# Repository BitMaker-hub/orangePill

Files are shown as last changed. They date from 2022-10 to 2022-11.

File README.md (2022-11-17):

# The Orange Pill
## Description
The OrangePill is a new social mechanism to onboard, gift, transfer or sell bitcoin in a physical, safe and reusable way.

It is a real HW Orange Pill that can be used in a community as cash. It also can be the entry point for those who doesn't know anything about Bitcoin and the best, it can be used as many times you want. 

## ATTENTION! This project is still in developement and must be tested on tesnet

## How can I use it?
Receive 💊 ➡️ Create 🌱💦 ➡️ Save ₿ 🔐➡️ Give it away

Receive 🔐 💊 ➡️ Unlock 🌱 ₿ ➡️ Reboot 💊 ➡️ Repeat with others 🔄

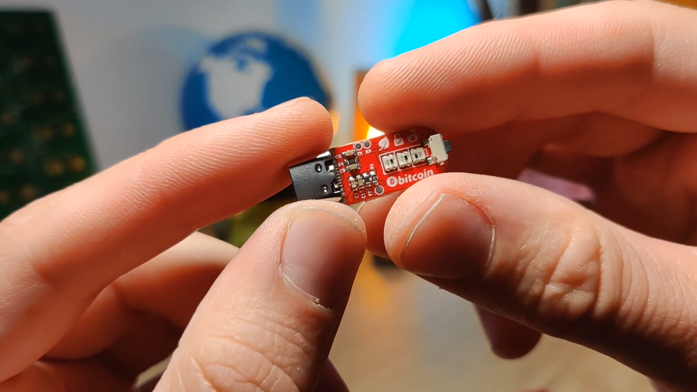
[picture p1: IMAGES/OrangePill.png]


## How it works?
### PILL AS A KEYBOARD
The OrangePill works as a input HID device, it emulates keyboard strokes. Every time you push it's button sends keystrokes.
It don't need any specific app to work. Works on any device or pc, you just need to open a notepad or any text editor and press the pill button.

Posible inputs:

- One push:   Shows current status, display options and show xpub or mnemonic depending of it's state.
- Two pushes: Shows # times pill was used, public gpg of interal hw + signed message.
- Hold 5 sec: Depending of it's state > Start seed generation / Unlock seed / Reset pill
- SHAKE: During seed generation or seed unlock.

##PILL STATES

The orangePill has currently three sates.

VIRGIN: No seed present. Needs to generate entropy. 
LOCKED: Seed present. When you make one push you can only see xpub.
UNLOCKED: Seed revealed. When you make one push you can see mnemonic.

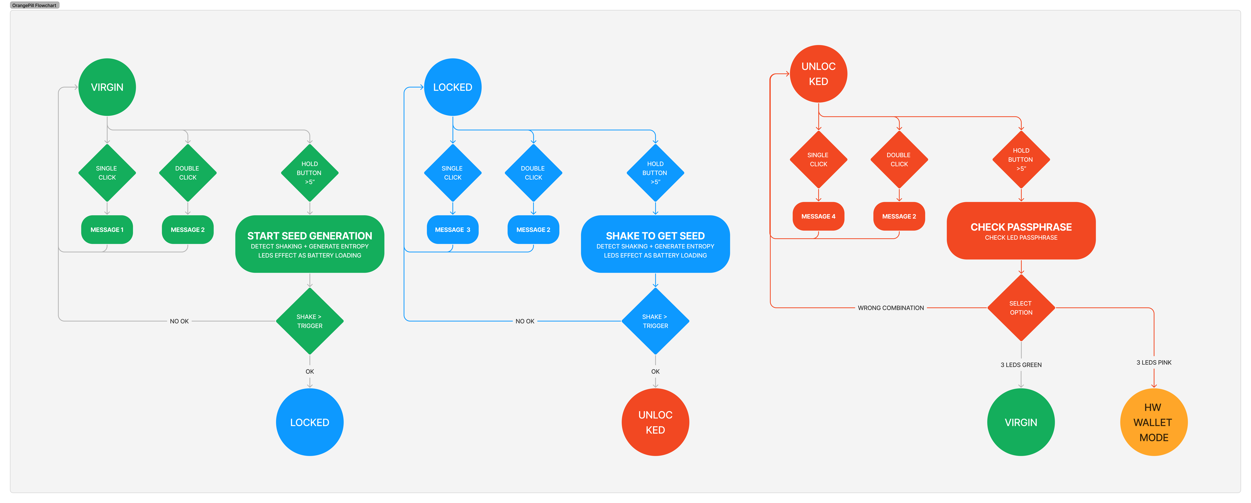
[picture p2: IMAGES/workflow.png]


## HW Specifictions
- ESP32S2
- LEDs WS2812B
- Button
- Accelerometer KXTJ3-1057
- ATTEC608A



## Libraires
- Main library -> <a href="https://www.arduino.cc/reference/en/libraries/ubitcoin/">uBitcoin</a>
- Adafruit_NeoPixel
- kxtj3-1057
- hidkeyboard

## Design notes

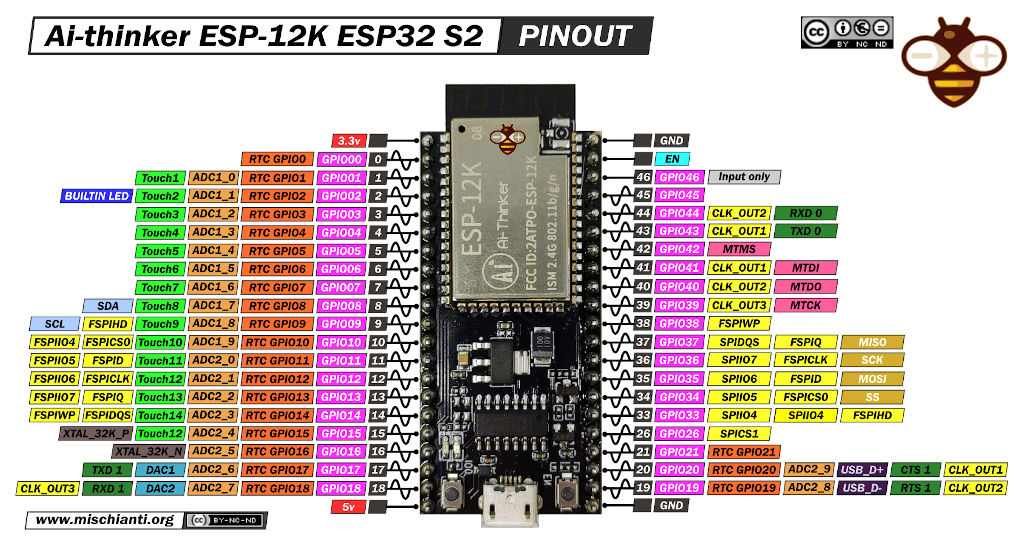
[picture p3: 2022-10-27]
SOFTWARE/Ai-thinker-ESP-12K-ESP32-S2-pinout-mischianti-low.jpg

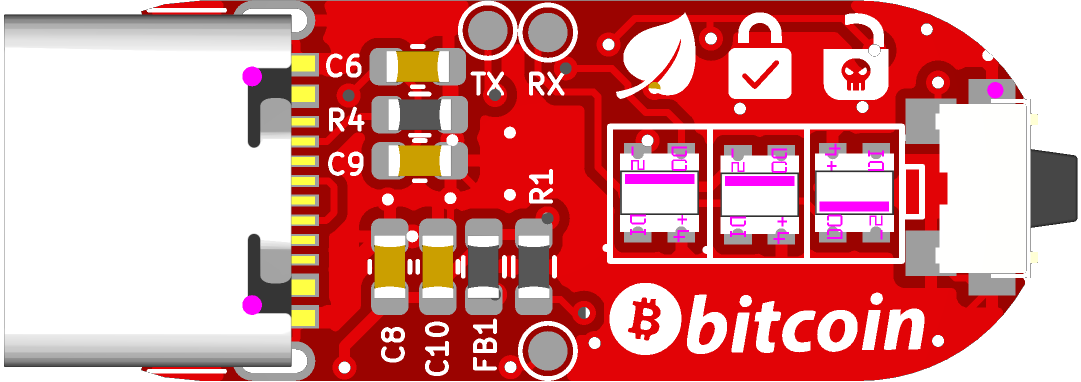
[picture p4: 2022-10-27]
PCB/Images/8e9199de238b4486b2469e8c72638f28.png

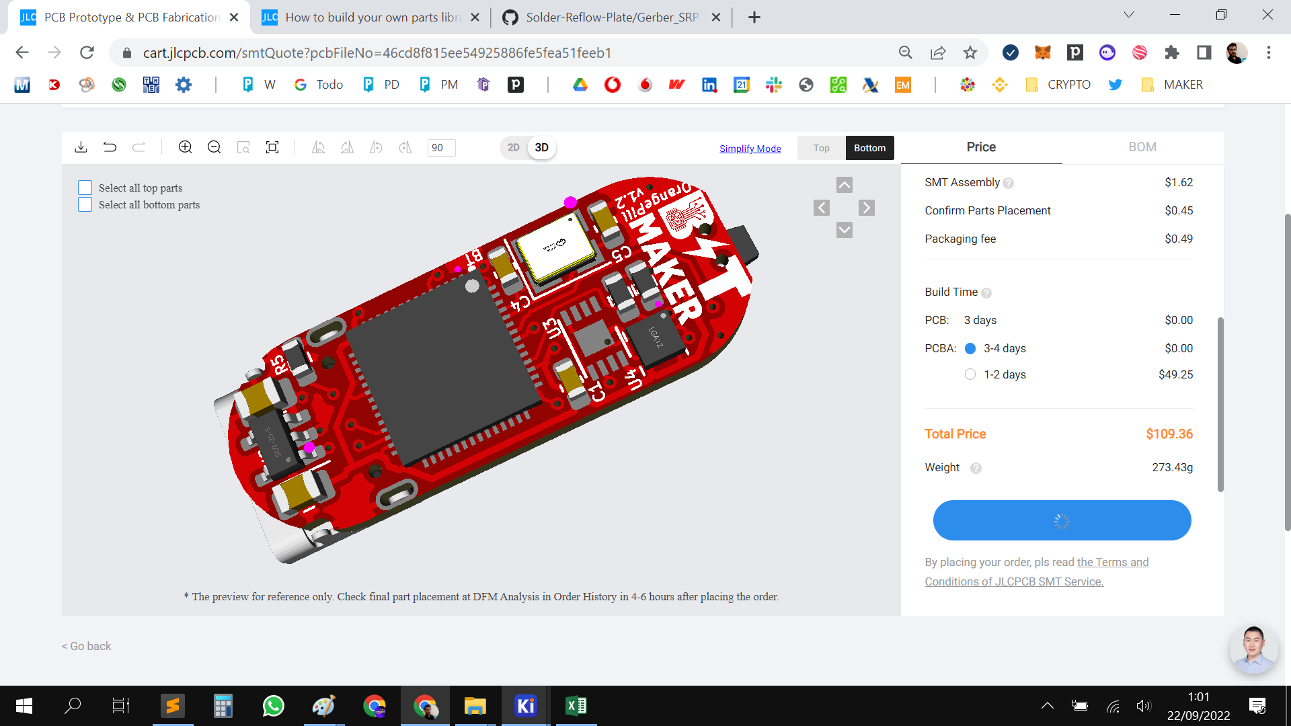
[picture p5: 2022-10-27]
PCB/Images/orangepill.png

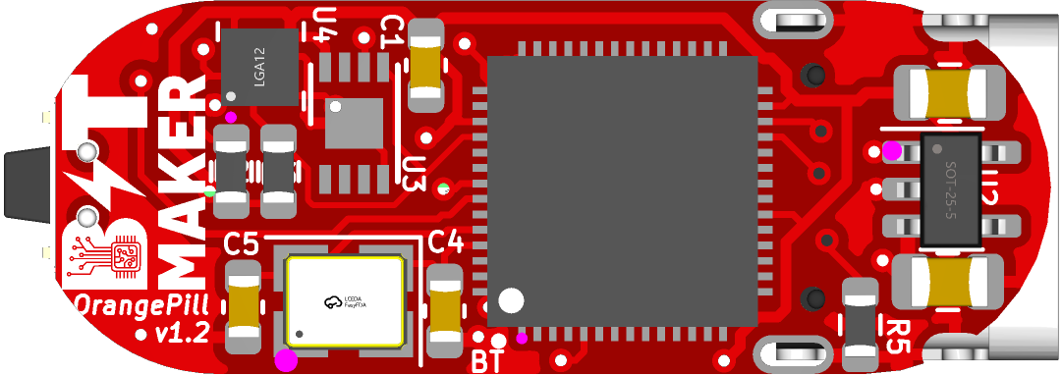
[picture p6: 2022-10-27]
PCB/Images/d6f5790a019c45c9bf4b03b32c207812.png

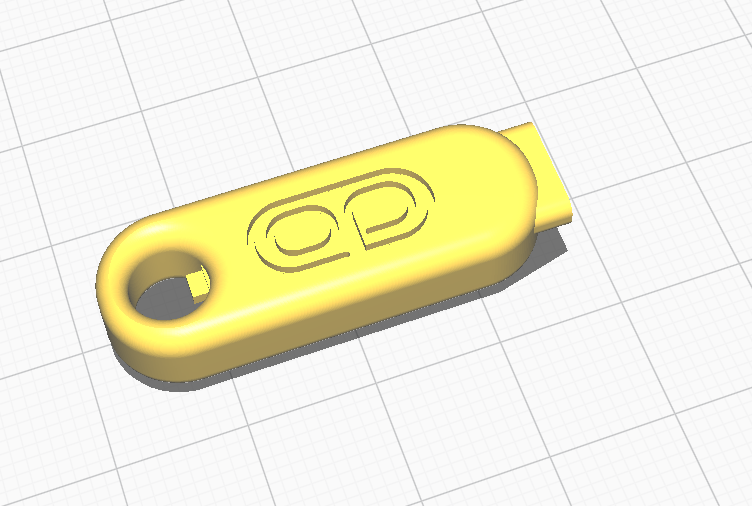
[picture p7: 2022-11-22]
IMAGES/pillEpoxi.png

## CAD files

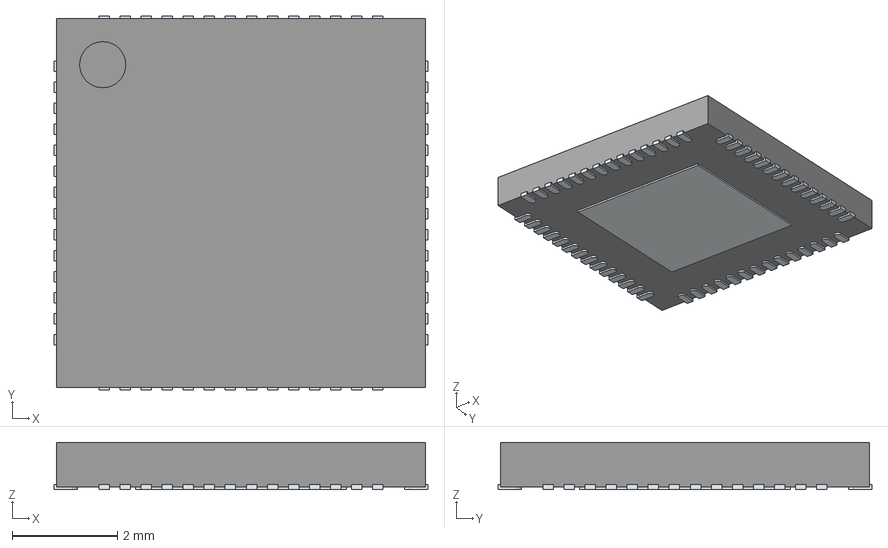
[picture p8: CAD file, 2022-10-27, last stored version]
PCB/Llibreries/ESP32-S2FN4R2.stp
7.10 x 7.10 x 0.9 mm
ThermalPin
PinsArrayLR
PinsArrayTB

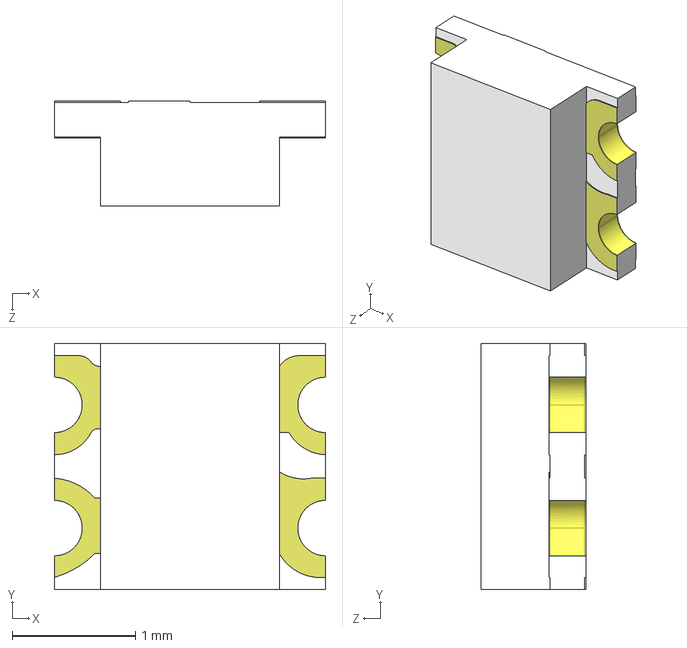
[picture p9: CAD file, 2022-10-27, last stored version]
PCB/Llibreries/WS2812B-2020.stp
2.20 x 2.00 x 0.85 mm

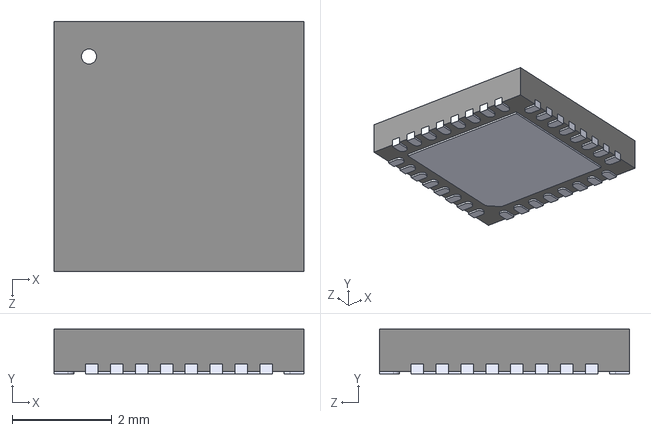
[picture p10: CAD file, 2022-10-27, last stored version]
PCB/Llibreries/ESP32-C3FH4.step
5.00 x 0.9 x 5.00 mm

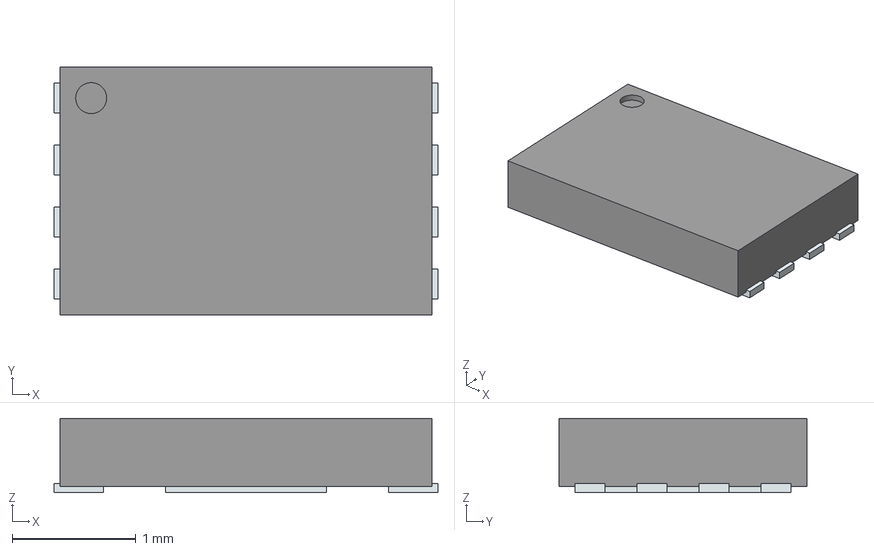
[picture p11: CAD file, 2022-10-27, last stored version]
PCB/Llibreries/ATECC508A-MAHCZ-S.stp
3.10 x 2.00 x 0.6 mm
ThermalPin
PinsArrayLR

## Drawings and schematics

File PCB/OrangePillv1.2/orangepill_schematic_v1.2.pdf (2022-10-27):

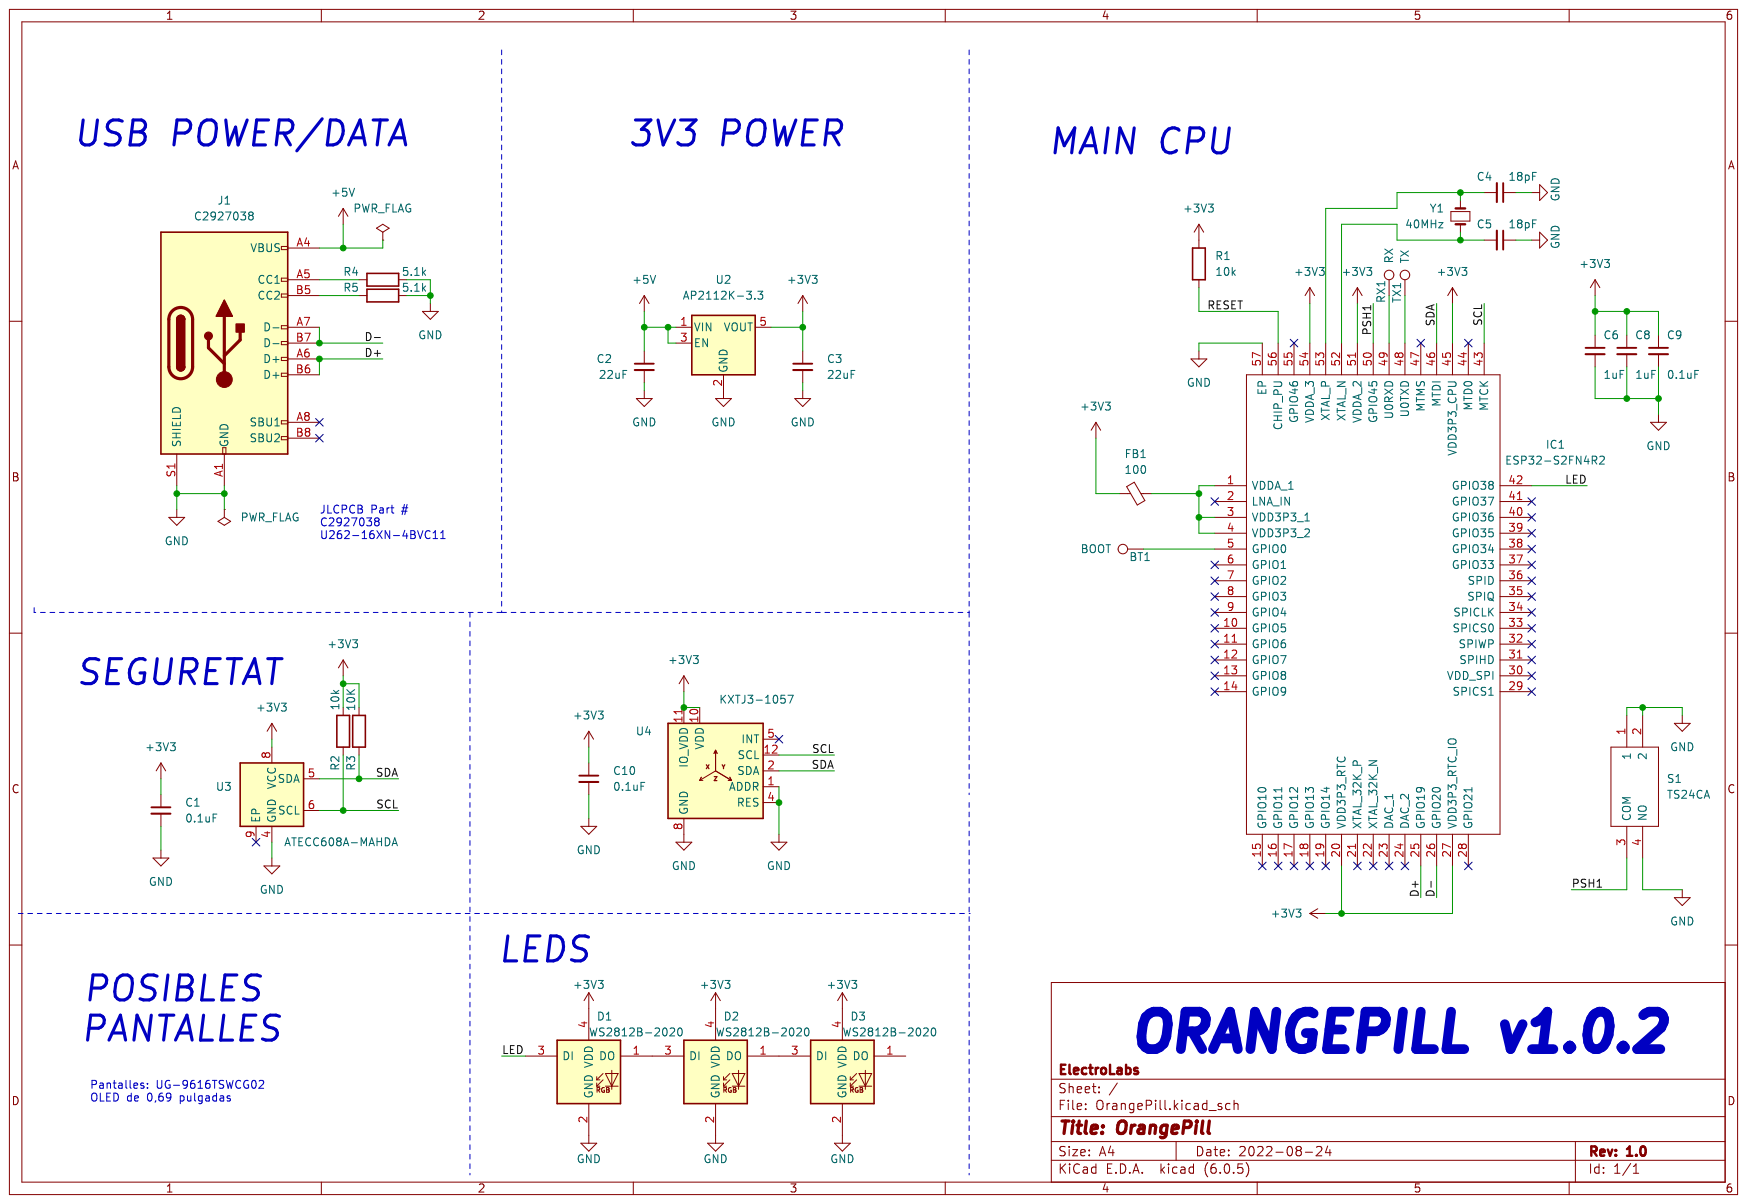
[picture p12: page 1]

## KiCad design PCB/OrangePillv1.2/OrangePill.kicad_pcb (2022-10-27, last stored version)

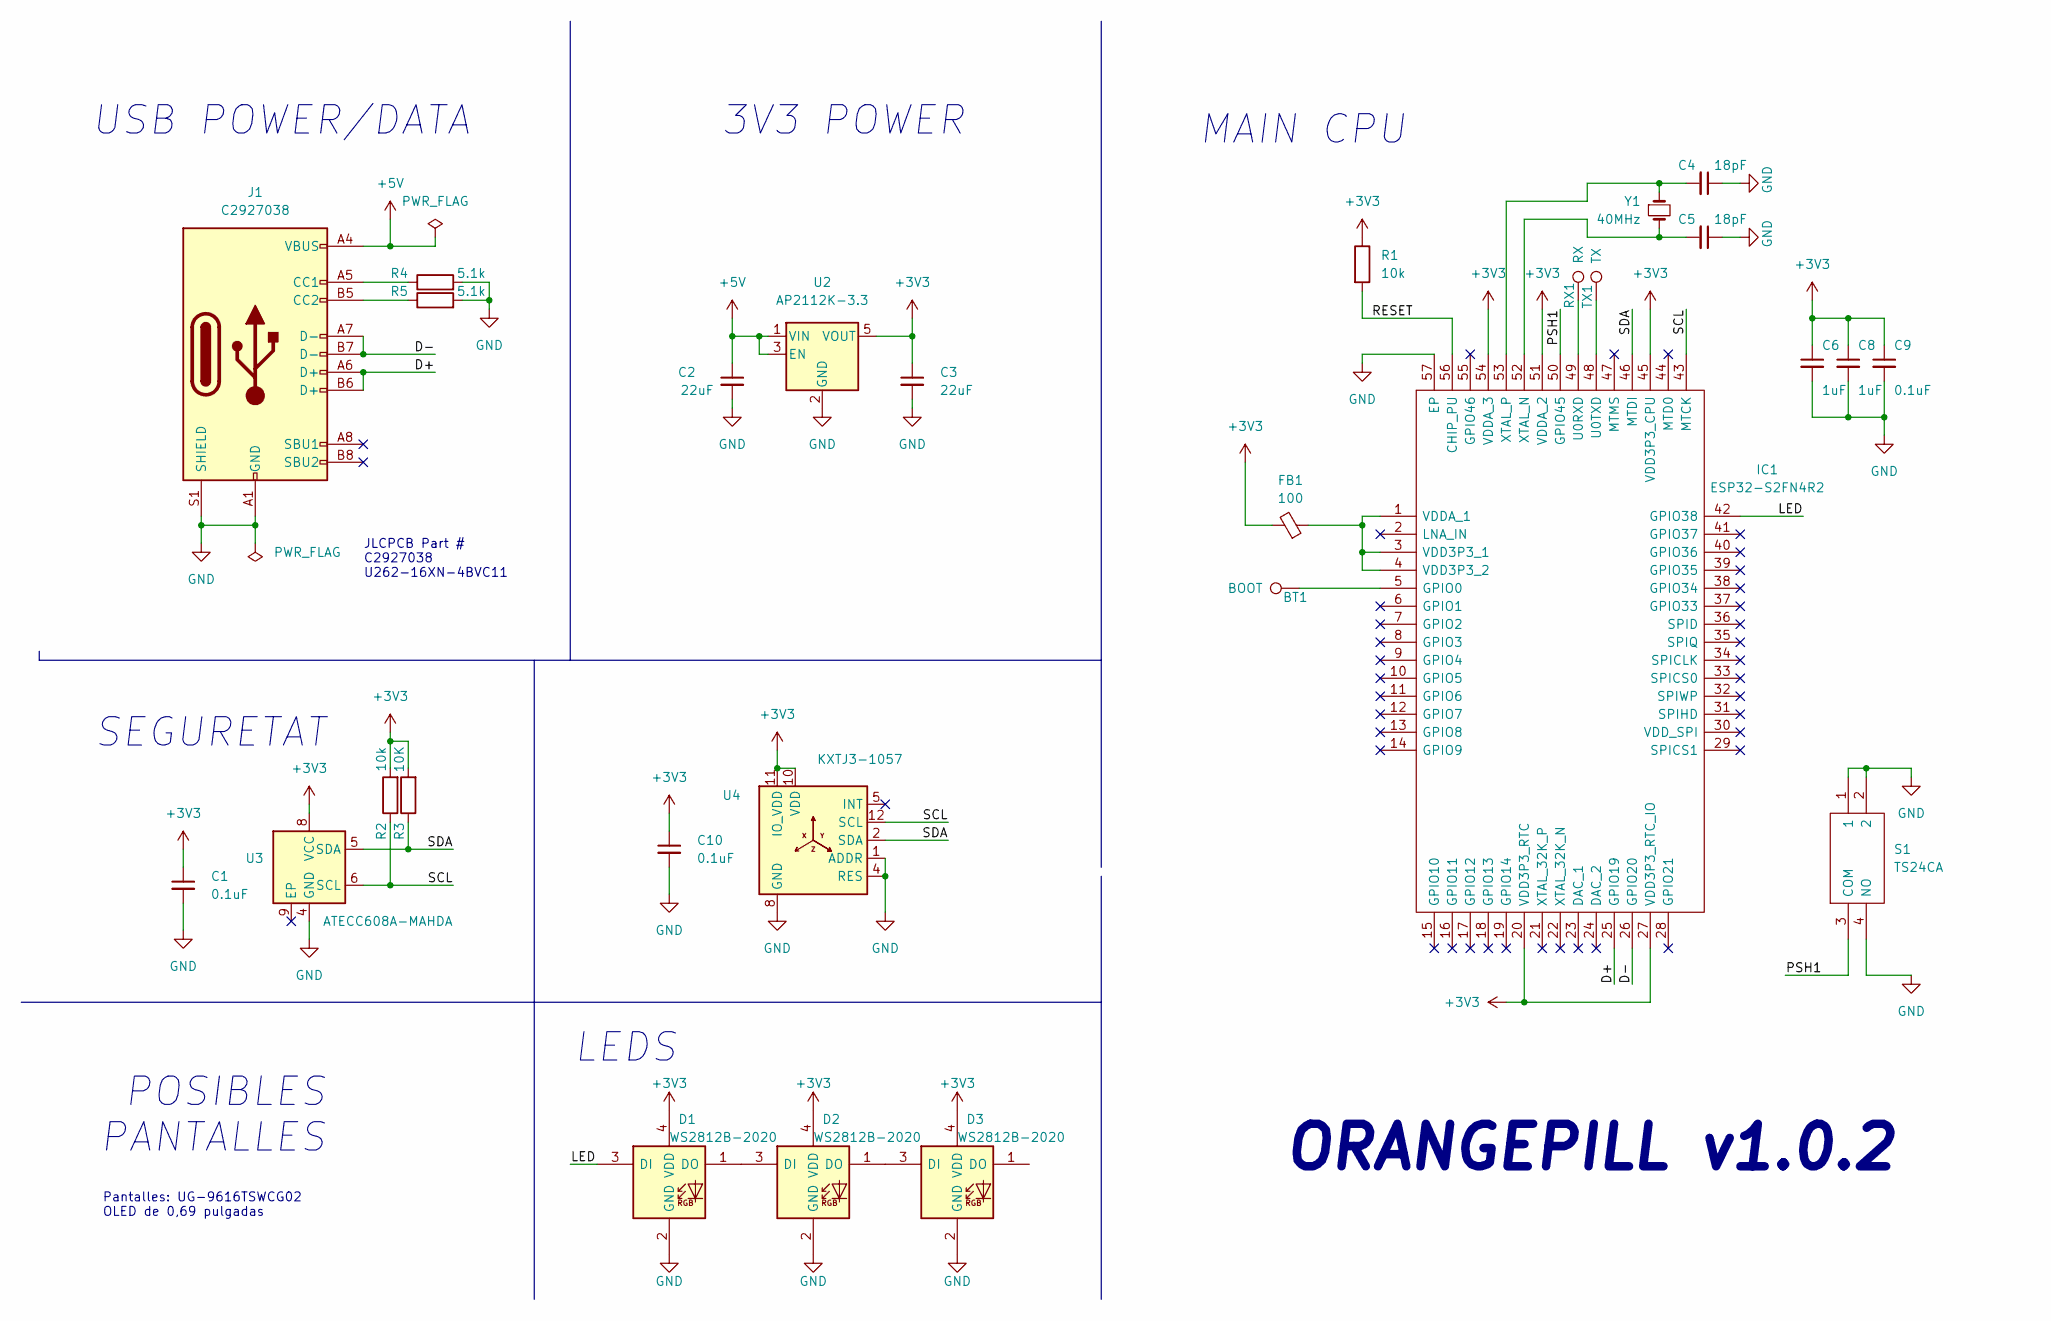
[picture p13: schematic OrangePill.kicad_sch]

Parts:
BT1: BOOT; TestPoint_Pad_D1.5mm
C1, C9, C10: 0.1uF; C_0603_1608Metric
C2, C3: 22uF; C_0805_2012Metric
C4, C5: 18pF; C_0603_1608Metric
C6, C8: 1uF; C_0603_1608Metric
D1, D2, D3: WS2812B-2020; WS2812B2020; Manufacturer_Part_Number WS2812B-2020
FB1: 100; R_0603_1608Metric
IC1: ESP32-S2FN4R2; QFN40P700X700X90-57N-D; Manufacturer_Part_Number ESP32-S2FN4R2; Mouser Part Number 356-ESP32-S2FN4R2
J1: C2927038; USB_C_Receptacle_XKB_U262-16XN-4BVC11
R1, R2: 10k; R_0603_1608Metric
R3: 10K; R_0603_1608Metric
R4, R5: 5.1k; R_0603_1608Metric
RX1: RX; TestPoint_Pad_D1.0mm
S1: TS24CA; Manufacturer_Part_Number TS24CA
TX1: TX; TestPoint_Pad_D1.0mm
U2: AP2112K-3.3; SOT-23-5
U3: ATECC608A-MAHDA; DFN-8-1EP_3x2mm_P0.5mm_EP1.3x1.5mm
U4: KXTJ3-1057; Kionix_LGA-12_2x2mm_P0.5mm_LayoutBorder2x4y
Y1: 40MHz; Crystal_SMD_3225-4Pin_3.2x2.5mm

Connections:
+3V3: C1.1, C3.1, C6.1, C8.1, C9.1, C10.1, D1.4 (VDD), D2.4 (VDD), D3.4 (VDD), FB1.2, IC1.20 (VDD3P3_RTC), IC1.27 (VDD3P3_RTC_IO), IC1.45 (VDD3P3_CPU), IC1.51 (VDDA_2), IC1.54 (VDDA_3), R1.1, R2.2, R3.2, U2.5 (VOUT), U3.8 (VCC), U4.3 (IO_VDD), U4.7 (VDD), U4.10 (VDD), U4.11 (IO_VDD)
+5V: C2.1, J1.A4 (VBUS), J1.A9 (VBUS), J1.B4 (VBUS), J1.B9 (VBUS), U2.1 (VIN), U2.3 (EN)
/D+: IC1.25 (GPIO19), J1.A6 (D+), J1.B6 (D+)
/D-: IC1.26 (GPIO20), J1.A7 (D-), J1.B7 (D-)
/LED: D1.3 (DI), IC1.42 (GPIO38)
/PSH1: IC1.50 (GPIO45), S1.3 (COM)
/RESET: IC1.56 (CHIP_PU), R1.2
/SCL: IC1.43 (MTCK), R2.1, U3.6 (SCL), U4.12 (SCL)
/SDA: IC1.46 (MTDI), R3.1, U3.5 (SDA), U4.2 (SDA)
GND: C1.2, C2.2, C3.2, C4.1, C5.1, C6.2, C8.2, C9.2, C10.2, D1.2 (GND), D2.2 (GND), D3.2 (GND), IC1.57 (EP), J1.A1 (GND), J1.A12 (GND), J1.B1 (GND), J1.B12 (GND), J1.S1 (SHIELD), R4.2, R5.2, S1.1, S1.2, S1.4 (NO), U2.2 (GND), U3.4 (GND), U3.9 (EP), U4.1 (ADDR), U4.4 (RES), U4.6 (GND), U4.8 (GND), U4.9 (GND)
unnamed: BT1.1, IC1.5 (GPIO0)
unnamed: C4.2, IC1.53 (XTAL_P), Y1.1
unnamed: C5.2, IC1.52 (XTAL_N), Y1.2
unnamed: D1.1 (DO), D2.3 (DI)
unnamed: D2.1 (DO), D3.3 (DI)
unnamed: FB1.1, IC1.1 (VDDA_1), IC1.3 (VDD3P3_1), IC1.4 (VDD3P3_2)
unnamed: IC1.48 (U0TXD), TX1.1
unnamed: IC1.49 (U0RXD), RX1.1
unnamed: J1.A5 (CC1), R4.1
unnamed: J1.B5 (CC2), R5.1

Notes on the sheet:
ORANGEPILL v1.0.2
POSIBLES PANTALLES
JLCPCB Part # C2927038 U262-16XN-4BVC11
LEDS
Pantalles: UG-9616TSWCG02 OLED de 0,69 pulgadas
SEGURETAT
MAIN CPU
USB POWER/DATA
3V3 POWER

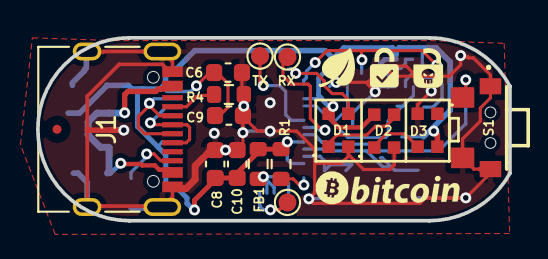
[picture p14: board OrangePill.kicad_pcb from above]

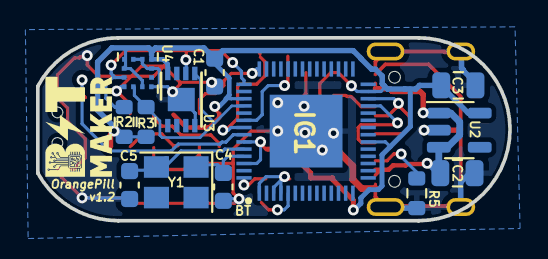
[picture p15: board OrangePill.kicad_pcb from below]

Board: 2 copper layers, 26.2 x 10.2 mm, 29 parts (13 on the bottom side), 20 nets.

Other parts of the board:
fiducial: Fiducial_0.5mm_Mask1.5mm

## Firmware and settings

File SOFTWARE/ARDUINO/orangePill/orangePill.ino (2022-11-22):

#include "gpio.h"
#include "btc.h"
#include "workflow.h"
#include "GlobalVARS.h"

sPILL myPill;

void setup() {

  pinMode(BUTTON_PIN, INPUT_PULLUP);            // Init pushbutton pin
  Serial.begin(SERIAL_BAUD);                    // Init Serial port
  EEPROMsetup();                                // Init EEPROMdata
  LedSetup();                                   // Init neopixels leds
  AccSetup();                                   // Init Accelerometer
  initUSBKeyboard();                            // Init USB Keyboard emulation
  initWallet();                                 // Init wallet data
}


void loop() {
  showInitEffect();

  while(true){
    int buttonState = checkButton();

    switch(myPill.State){
      case STATE_VIRGIN:   doVirginState(buttonState); break;
      case STATE_SEEDING:  doSeedingState(buttonState); break;
      case STATE_LOCKED:   doLockedState(buttonState); break;
      case STATE_OPENPILL: doOpenPill(buttonState); break;
      case STATE_UNLOCKED: doUnlockedState(buttonState); break;
    }
    delay(10);
  }
}

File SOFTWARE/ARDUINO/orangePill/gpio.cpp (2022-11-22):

#include <Adafruit_NeoPixel.h>
#include <EEPROM.h>
#include "GlobalVARS.h"
#include "gpio.h"
#include "kxtj3-1057.h"
#include "Wire.h"

// Enable Serial debbug on Serial UART to see registers wrote
#define KXTJ3_DEBUG Serial

float   sampleRate = 6.25;  // HZ - Samples per second - 0.781, 1.563, 3.125, 6.25, 12.5, 25, 50, 100, 200, 400, 800, 1600Hz
uint8_t accelRange = 2;     // Accelerometer range = 2, 4, 8, 16g

// Declare our NeoPixel strip object:
Adafruit_NeoPixel strip(LED_COUNT, LED_PIN, NEO_GRB + NEO_KHZ800);

KXTJ3 myACC(0x0E); // Address can be 0x0E or 0x0F

extern sPILL myPill;

/***********************💊 EEPROM DATA ******************************/

void EEPROMsetup(){
  
  EEPROM.begin(EEPROM_SIZE);
  
  /********💊 READ PILL STATE ************/
  myPill.State = EEPROM.read(0);
  if(myPill.State>STATE_UNLOCKED) myPill.State = STATE_VIRGIN;
  
  /********💊 READ MNMONIC ************/
  String mnemonic="";
  if(EEPROM.read(1) == STX){
    for(uint16_t i=2; i<400; i++){
      uint8_t nm = EEPROM.read(i);
      if(nm == ETX) break;
      mnemonic = mnemonic + char(nm);
    }
  }
  myPill.mnemonic = mnemonic;
  Serial.print("Current mnemonic: "); Serial.println(mnemonic);
  
}

void saveMnemonic(String mnemonic){

  uint16_t i;
  for(i=2; i<(mnemonic.length()+2); i++){
    EEPROM.write(i, mnemonic[i-2]);
  }
  EEPROM.write(i,3);
  EEPROM.write(1,STX);
  delay(10);
  EEPROM.commit();
}

/***********************💊 LED EFFECTS ******************************/
void LedSetup() {
  strip.begin();           // INITIALIZE NeoPixel strip object (REQUIRED)
  strip.show();            // Turn OFF all pixels ASAP
  strip.setBrightness(40); // Set BRIGHTNESS to about 1/5 (max = 255)
}

void colorWipe(uint32_t color, int wait) {
  for(int i=0; i<strip.numPixels(); i++) { // For each pixel in strip...
    strip.setPixelColor(i, color);         //  Set pixel's color (in RAM)
    strip.show();                          //  Update strip to match
    delay(wait);                           //  Pause for a moment
  }
}
void colorWipeBack(uint32_t color, int wait) {
  for(int i=strip.numPixels(); i>0; i--) { // For each pixel in strip...
    strip.setPixelColor(i-1, color);         //  Set pixel's color (in RAM)
    strip.show();                          //  Update strip to match
    delay(wait);                           //  Pause for a moment
  }
}

// Rainbow cycle along whole strip. Pass delay time (in ms) between frames.
void rainbow(int wait) {
  for(long firstPixelHue = 0; firstPixelHue < 1*65536; firstPixelHue += 256) {
    strip.rainbow(firstPixelHue);
    strip.show(); // Update strip with new contents
    delay(wait);  // Pause for a moment
  }
}

//Init efect on leds
void showInitEffect(){
                            //RED-GREEN-BLUE
  //uint32_t color = strip.Color(0,   255,   0); //Green
  //rainbow(6); 
  setLedsColor(COLOR_NONE, COLOR_NONE, COLOR_NONE);
  delay(100);

  uint32_t color = COLOR_GREEN;
  switch(myPill.State){
     case STATE_VIRGIN:  color = COLOR_GREEN; break;
     case STATE_LOCKED: color = COLOR_BLUE; break;
     case STATE_UNLOCKED: color = COLOR_RED; break;
  }
  
  colorWipe(color, 100);
  delay(100);
  colorWipe(COLOR_NONE, 100);
  colorWipeBack(color, 100);
  delay(100);
  colorWipeBack(COLOR_NONE, 100);
}

void setLedsColor(int Led1, int Led2, int Led3) {
    strip.setPixelColor(0, Led1);
    strip.setPixelColor(1, Led2);
    strip.setPixelColor(2, Led3);
    strip.show();
}

//Blink all 3 leds 
void blinkAllLeds(uint32_t color){
  for(int i=0; i<4; i++){
    strip.setPixelColor(0, color);
    strip.setPixelColor(1, color);
    strip.setPixelColor(2, color);
    strip.show();
    delay(150);
    strip.setPixelColor(0, COLOR_NONE);
    strip.setPixelColor(1, COLOR_NONE);
    strip.setPixelColor(2, COLOR_NONE);
    strip.show();
    delay(150);
  }
  delay(500);
}


/*********************💊 ACCELEROMETER *****************/
void AccSetup(){
  Wire.begin(I2C_SDA, I2C_SCL); 
  
  if( myACC.begin(sampleRate, accelRange) != 0 )
  {
    Serial.print("Failed to initialize IMU.\n");
  }
  else
  {
    Serial.print("IMU initialized.\n");
  }
  
  // Detection threshold, movement duration and polarity
  myACC.intConf(123, 1, 10, HIGH);

  uint8_t readData = 0;

  // Get the ID:
  myACC.readRegister(&readData, KXTJ3_WHO_AM_I);
  Serial.print("Who am I? 0x");
  Serial.println(readData, HEX);
}

void AccelerometerRead(){
  myACC.standby( false );

  float acc_x = myACC.axisAccel( X );
  float acc_y = myACC.axisAccel( Y );
  float acc_z = myACC.axisAccel( Z );
  /*Serial.print(acc_x);Serial.print(",");
  Serial.print(acc_y);Serial.print(",");
  Serial.println(acc_z);*/

  if(( acc_x > SHAKE_TRIGGER_H) || ( acc_x < SHAKE_TRIGGER_L) || 
     ( acc_y > SHAKE_TRIGGER_H) || ( acc_y < SHAKE_TRIGGER_L) || 
     ( acc_z > SHAKE_TRIGGER_H) || ( acc_z < SHAKE_TRIGGER_L))
    myPill.shakeCounts++;
  
  myACC.standby( true );
}

/*****************💊 BUTTON DETECTION *********************/
byte butLst;
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

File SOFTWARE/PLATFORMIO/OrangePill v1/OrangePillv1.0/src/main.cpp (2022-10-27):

#include <Arduino.h>
#include <SPI.h>
#include <SD.h>
#include "leds.h"

#include "hidkeyboard.h"
HIDkeyboard Keyboard;

const int buttonPin = 45;          // input pin for pushbutton
int previousButtonState = HIGH;   // for checking the state of a pushButton
int counter = 0;                  // button push counter

void setup() {
  // make the pushButton pin an input:
  pinMode(buttonPin, INPUT_PULLUP);
  // initialize control over the keyboard:
  Serial.begin(115200);
  Keyboard.begin();
  LedSetup();
  //USB.begin();
}

void loop() {
  Ledloop();
  // read the pushbutton:
  int buttonState = digitalRead(buttonPin);
  // if the button state has changed,
  if ((buttonState != previousButtonState)
      // and it's currently pressed:
      && (buttonState == LOW)) {
    // increment the button counter
    Serial.print("pressed - ");
    counter++;
    // type out a message
    String text = "You pressed the button " + String(counter) + "times.\n";
    Serial.println(Keyboard.sendString(text)?"OK":"FAIL");
    /*Keyboard.sendString("You pressed the button ");
    Keyboard.sendString(counter);
    Keyboard.sendString(" times.\n");*/
  }
  // save the current button state for comparison next time:
  previousButtonState = buttonState;
}

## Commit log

2022-10-27 First commit initial tests
    [ATECC508A-MAHCZ-S.stp, ESP32-C3FH4.step, ESP32-S2FN4R2.stp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]
2022-10-27 Joined accelerometer tests
    - TODO properly give fucntionality before adding ATTEC
2022-11-06 Major Pill changes
    - Code structure
    - Moving out gerbers
    - Added all logic of pill
    - Added accelerometer work
    - Added button work
    - Added led effects
    [ATECC508A-MAHCZ-S.stp, ESP32-C3FH4.step, ESP32-S2FN4R2.stp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]
2022-11-22 Adding uBitcoin functions
    [OK] - Generate seed
    [OK] - Show xpub
    [OK] - Show seed words
    [OK] - Save it in EEPROM
    [OK] - Get seed from EEPROM
    TODO:
    - Finish text including xpuv and seed when button is presed
    - Encrypt & Decrypt EEPROM data
    - Last step color combination to reboot the pill
    - PGP key
    [GlobalVARS.h, gpio.cpp, orangePill.ino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]
